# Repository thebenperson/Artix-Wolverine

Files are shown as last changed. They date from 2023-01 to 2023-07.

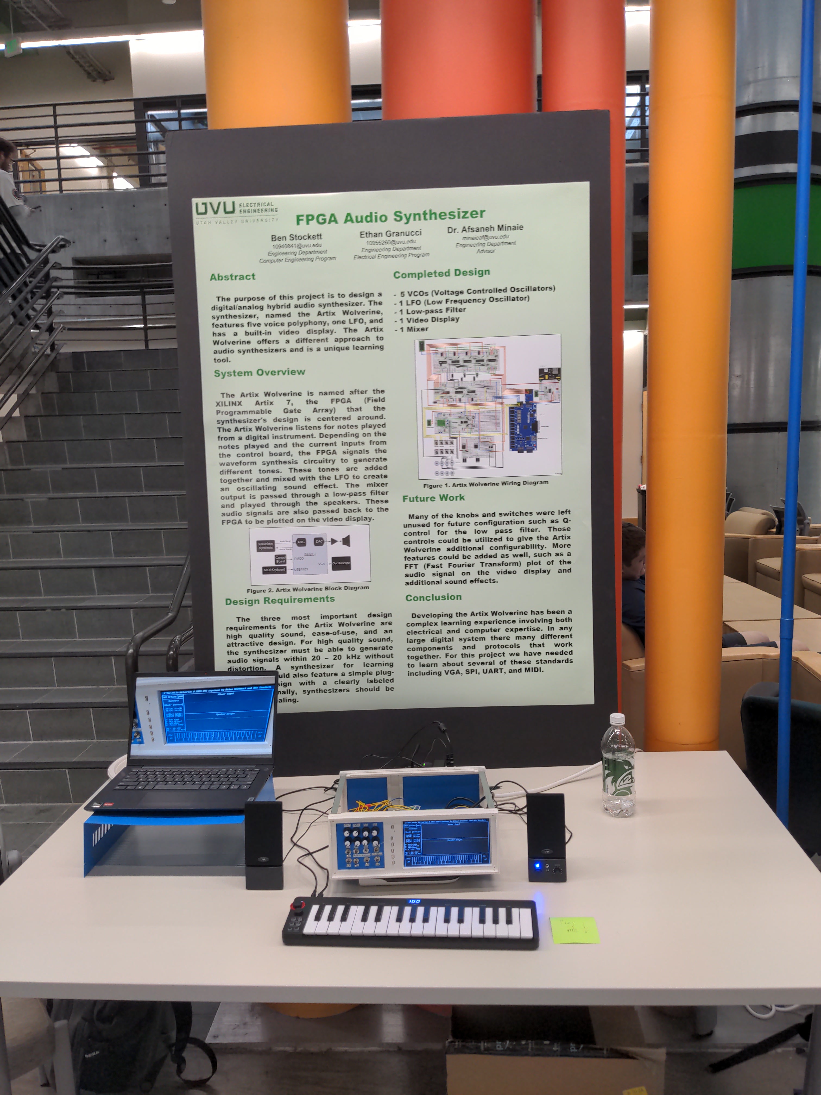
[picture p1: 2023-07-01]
Capstone Day.jpg

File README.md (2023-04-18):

# Artix Wolverine
## 2023 UVU Capstone Project
### Ethan Granucci and Ben Stockett

---

### Project Structure:

```
.
├── bin
│   └── *
├── Makefile
├── README.md
├── res
│   ├── font.psfu
│   └── text.txt
├── src
│   ├── adc.sv
│   ├── agv.sv
│   ├── constraints.xdc
│   ├── dac.sv
│   ├── font.hex
│   ├── font.sv
│   ├── midi.sv
│   ├── oediv.sv
│   ├── text.hex
│   └── top.sv
├── tests
│   └── *
├── tools
│   ├── genfont.sh
│   ├── gentext.sh
│   └── midi.sh
└── Wiring Diagram.fzz
```

### `bin/`: Executables

---

`Makefile`: A [Makefile](https://www.gnu.org/software/make) to build simulations with the [Icarus Verilog](http://iverilog.icarus.com) simulator.

`README.md`: This document.

---

### `res/`: Data and resources
- `font.psfu`: The [PC screen font](https://en.wikipedia.org/wiki/PC_Screen_Font) used in this project.
- `text.txt`: Static text to be displayed on the screen.

---

### `src/`: Project sources
- `adc.sv`: Logic for the analog to digital converter.
- `agv.sv`: Generation of VGA timing signals.
- `constraints.xdc`: Maps port names to their corresponding pins on the Basys 3 FPGA.
- `dac.sv`: Logic for the digital to analog converter.
- `font.hex`: Contents of the font ROM.
- `font.sv`: Retrieves bitmaps corresponding to character numbers.
- `midi.sv`: A MIDI reciever module used to detect keyboard events.
- `oediv.sv`: Logic for drawing characters and numbers.
- `text.hex`: Contents of the ROM for static text to be displayed on the screen.
- `top.sv`: The top module.

---

### `tests/`: Testbenches

---

### `tools/`: Various scripts
- `genfont.sh`: A script to extract the characters we want from the font.
- `gentext.sh`: A script to convert an ASCII text file to a binary encoding suitable for this project.
- `midi.sh`: A script to test the MIDI receiver module with [VMPK, a virtual MIDI keyboard](https://vmpk.sourceforge.io).

---

`Wiring Diagram.fzz`: The [Fritzing](https://fritzing.org) wiring diagram for this project.

---

## Icarus Verilog Simulation:

Running `make` in the project directory will build the simulation with the testbench for the top module by default. To change the testbench, set the makefile variable `test`.

> For example, to include the testbench for the font module, run `make test=font`.

Run `make test` to start the simulation.

### Note:

Icarus Verilog has some trouble with files that start with `v`. That's why `agv.sv` is not named `vga.sv` and `oediv.sv` is not named `video.sv`.

---

## Synthesis:

Synthesis needs to be performed in Xilinx Vivado. Run `make export` and import the contents of the `src/` folder into a new Vivado project.

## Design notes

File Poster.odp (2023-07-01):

## FPGA Audio Synthesizer

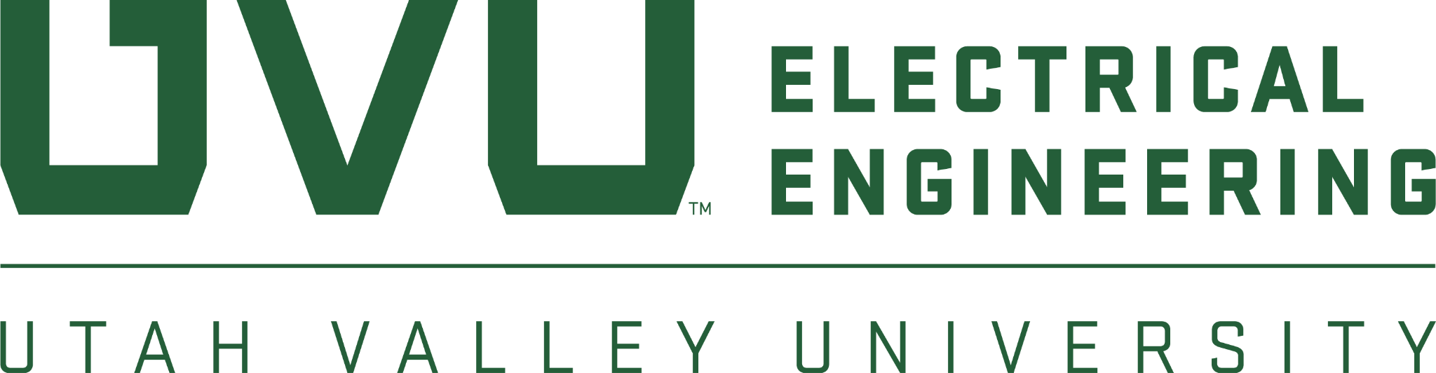
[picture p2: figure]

Ben Stockett

10940841@uvu.edu

Engineering Department

Computer Engineering Program

Abstract

The purpose of this project is to design a digital/analog hybrid audio synthesizer. The synthesizer, named the Artix Wolverine, features five voice polyphony, one LFO, and has a built-in video display. The Artix Wolverine offers a different approach to audio synthesizers and is a unique learning tool.

Ethan Granucci

10955260@uvu.edu

Engineering Department

Electrical Engineering Program

Dr. Afsaneh Minaie

minaieaf@uvu.edu

Engineering Department

Advisor

Completed Design

- 5 VCOs (Voltage Controlled Oscillators)

- 1 LFO (Low Frequency Oscillator)

- 1 Low-pass Filter

- 1 Video Display

- 1 Mixer

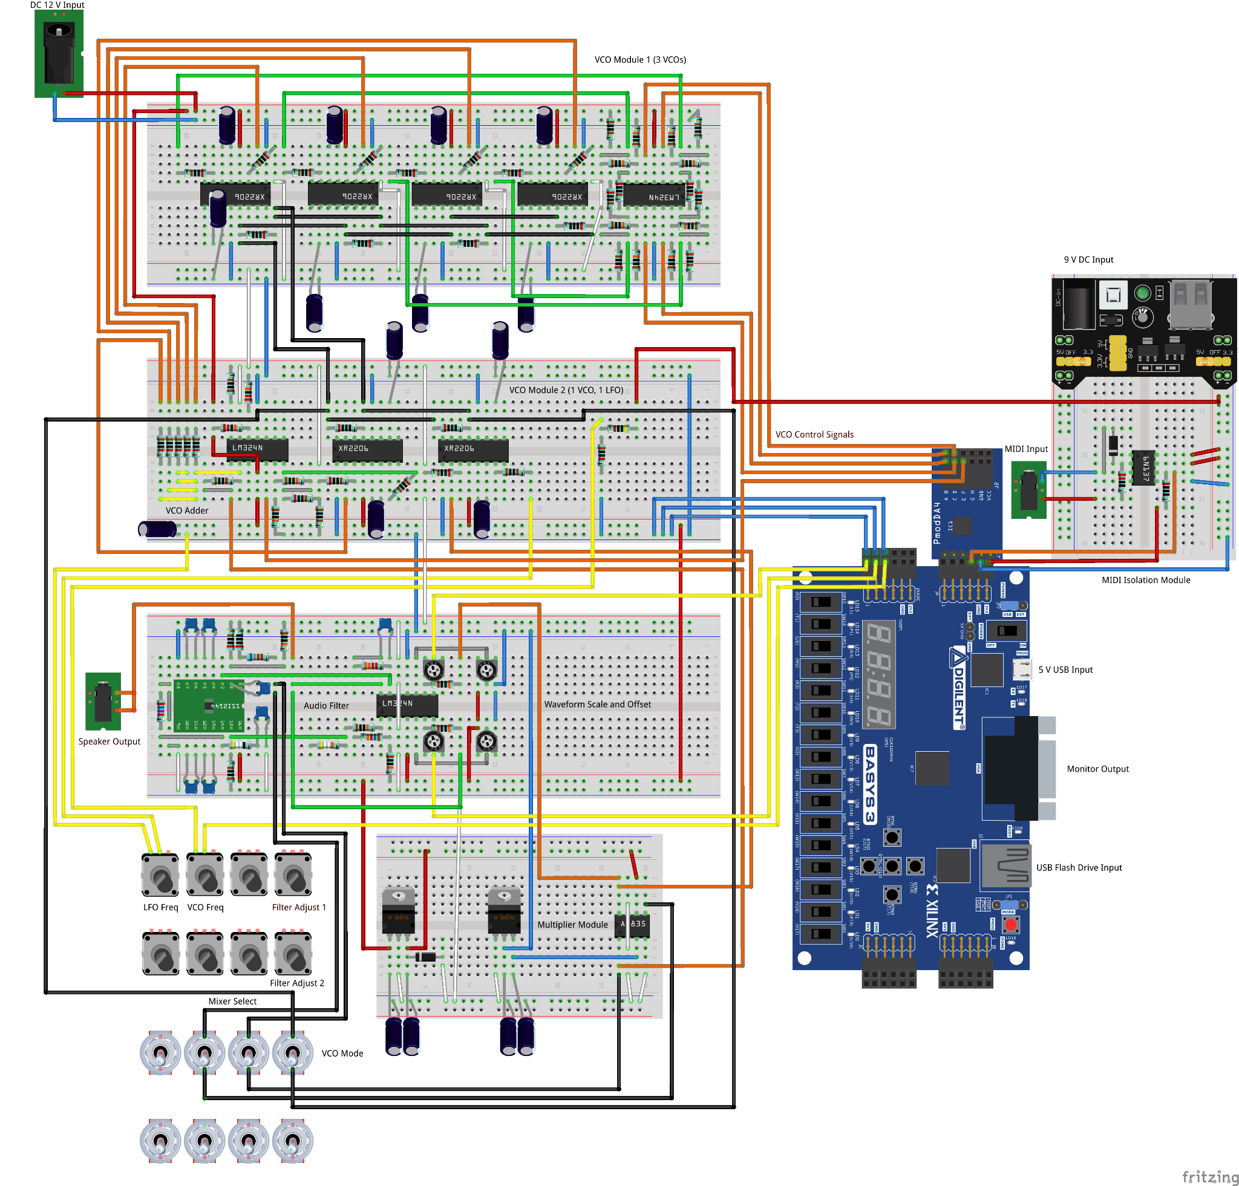
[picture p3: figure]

Figure 1. Artix Wolverine Wiring Diagram

Future Work

Many of the knobs and switches were left unused for future configuration such as Q-control for the low pass filter. Those controls could be utilized to give the Artix Wolverine additional configurability. More features could be added as well, such as a FFT (Fast Fourier Transform) plot of the audio signal on the video display and additional sound effects.

System Overview

The Artix Wolverine is named after the XILINX Artix 7, the FPGA (Field Programmable Gate Array) that the synthesizer's design is centered around. The Artix Wolverine listens for notes played from a digital instrument. Depending on the notes played and the current inputs from the control board, the FPGA signals the waveform synthesis circuitry to generate different tones. These tones are added together and mixed with the LFO to create an oscillating sound effect. The mixer output is passed through a low-pass filter and played through the speakers. These audio signals are also passed back to the FPGA to be plotted on the video display.

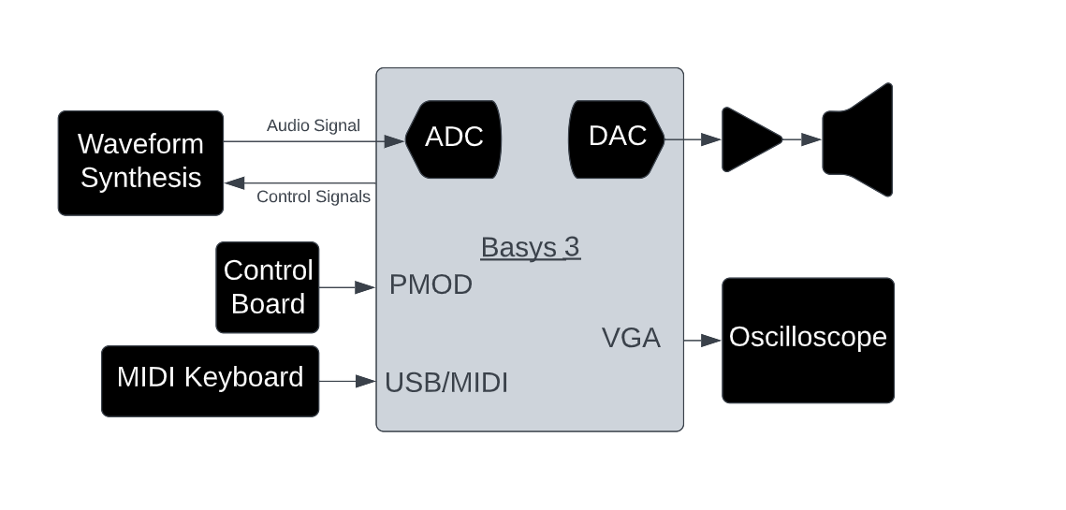
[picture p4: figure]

Figure 2. Artix Wolverine Block Diagram

Design Requirements

The three most important design requirements for the Artix Wolverine are high quality sound, ease-of-use, and an attractive design. For high quality sound, the synthesizer must be able to generate audio signals within 20 – 20 kHz without distortion. A synthesizer for learning purposes should also feature a simple plug-and-play design with a clearly labeled interface. Finally, synthesizers should be visually appealing.

Conclusion

Developing the Artix Wolverine has been a complex learning experience involving both electrical and computer expertise. In any large digital system there many different components and protocols that work together. For this project we have needed to learn about several of these standards including VGA, SPI, UART, and MIDI.

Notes: <number>

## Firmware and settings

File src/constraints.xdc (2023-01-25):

## This file is a general .xdc for the Basys3 rev B board
## To use it in a project:
## - uncomment the lines corresponding to used pins
## - rename the used ports (in each line, after get_ports) according to the top level signal names in the project

## Clock signal
#set_property -dict { PACKAGE_PIN W5   IOSTANDARD LVCMOS33 } [get_ports clk]
#create_clock -add -name sys_clk_pin -period 10.00 -waveform {0 5} [get_ports clk]

 set_property -dict { PACKAGE_PIN W5   IOSTANDARD LVCMOS33 } [get_ports clk]
 create_clock -add -name sys_clk_pin -period 10.00 -waveform {0 5} [get_ports clk]


## Switches
#set_property -dict { PACKAGE_PIN V17   IOSTANDARD LVCMOS33 } [get_ports {sw[0]}]
#set_property -dict { PACKAGE_PIN V16   IOSTANDARD LVCMOS33 } [get_ports {sw[1]}]
#set_property -dict { PACKAGE_PIN W16   IOSTANDARD LVCMOS33 } [get_ports {sw[2]}]
#set_property -dict { PACKAGE_PIN W17   IOSTANDARD LVCMOS33 } [get_ports {sw[3]}]
#set_property -dict { PACKAGE_PIN W15   IOSTANDARD LVCMOS33 } [get_ports {sw[4]}]
#set_property -dict { PACKAGE_PIN V15   IOSTANDARD LVCMOS33 } [get_ports {sw[5]}]
#set_property -dict { PACKAGE_PIN W14   IOSTANDARD LVCMOS33 } [get_ports {sw[6]}]
#set_property -dict { PACKAGE_PIN W13   IOSTANDARD LVCMOS33 } [get_ports {sw[7]}]
#set_property -dict { PACKAGE_PIN V2    IOSTANDARD LVCMOS33 } [get_ports {sw[8]}]
#set_property -dict { PACKAGE_PIN T3    IOSTANDARD LVCMOS33 } [get_ports {sw[9]}]
#set_property -dict { PACKAGE_PIN T2    IOSTANDARD LVCMOS33 } [get_ports {sw[10]}]
#set_property -dict { PACKAGE_PIN R3    IOSTANDARD LVCMOS33 } [get_ports {sw[11]}]
#set_property -dict { PACKAGE_PIN W2    IOSTANDARD LVCMOS33 } [get_ports {sw[12]}]
#set_property -dict { PACKAGE_PIN U1    IOSTANDARD LVCMOS33 } [get_ports {sw[13]}]
#set_property -dict { PACKAGE_PIN T1    IOSTANDARD LVCMOS33 } [get_ports {sw[14]}]
#set_property -dict { PACKAGE_PIN R2    IOSTANDARD LVCMOS33 } [get_ports {sw[15]}]


## LEDs
#set_property -dict { PACKAGE_PIN U16   IOSTANDARD LVCMOS33 } [get_ports {led[0]}]
#set_property -dict { PACKAGE_PIN E19   IOSTANDARD LVCMOS33 } [get_ports {led[1]}]
#set_property -dict { PACKAGE_PIN U19   IOSTANDARD LVCMOS33 } [get_ports {led[2]}]
#set_property -dict { PACKAGE_PIN V19   IOSTANDARD LVCMOS33 } [get_ports {led[3]}]
#set_property -dict { PACKAGE_PIN W18   IOSTANDARD LVCMOS33 } [get_ports {led[4]}]
#set_property -dict { PACKAGE_PIN U15   IOSTANDARD LVCMOS33 } [get_ports {led[5]}]
#set_property -dict { PACKAGE_PIN U14   IOSTANDARD LVCMOS33 } [get_ports {led[6]}]
#set_property -dict { PACKAGE_PIN V14   IOSTANDARD LVCMOS33 } [get_ports {led[7]}]
#set_property -dict { PACKAGE_PIN V13   IOSTANDARD LVCMOS33 } [get_ports {led[8]}]
#set_property -dict { PACKAGE_PIN V3    IOSTANDARD LVCMOS33 } [get_ports {led[9]}]
#set_property -dict { PACKAGE_PIN W3    IOSTANDARD LVCMOS33 } [get_ports {led[10]}]
#set_property -dict { PACKAGE_PIN U3    IOSTANDARD LVCMOS33 } [get_ports {led[11]}]
#set_property -dict { PACKAGE_PIN P3    IOSTANDARD LVCMOS33 } [get_ports {led[12]}]
#set_property -dict { PACKAGE_PIN N3    IOSTANDARD LVCMOS33 } [get_ports {led[13]}]
#set_property -dict { PACKAGE_PIN P1    IOSTANDARD LVCMOS33 } [get_ports {led[14]}]
#set_property -dict { PACKAGE_PIN L1    IOSTANDARD LVCMOS33 } [get_ports {led[15]}]


##7 Segment Display
#set_property -dict { PACKAGE_PIN W7   IOSTANDARD LVCMOS33 } [get_ports {seg[0]}]
#set_property -dict { PACKAGE_PIN W6   IOSTANDARD LVCMOS33 } [get_ports {seg[1]}]
#set_property -dict { PACKAGE_PIN U8   IOSTANDARD LVCMOS33 } [get_ports {seg[2]}]
#set_property -dict { PACKAGE_PIN V8   IOSTANDARD LVCMOS33 } [get_ports {seg[3]}]
#set_property -dict { PACKAGE_PIN U5   IOSTANDARD LVCMOS33 } [get_ports {seg[4]}]
#set_property -dict { PACKAGE_PIN V5   IOSTANDARD LVCMOS33 } [get_ports {seg[5]}]
#set_property -dict { PACKAGE_PIN U7   IOSTANDARD LVCMOS33 } [get_ports {seg[6]}]

#set_property -dict { PACKAGE_PIN V7   IOSTANDARD LVCMOS33 } [get_ports dp]

#set_property -dict { PACKAGE_PIN U2   IOSTANDARD LVCMOS33 } [get_ports {an[0]}]
#set_property -dict { PACKAGE_PIN U4   IOSTANDARD LVCMOS33 } [get_ports {an[1]}]
#set_property -dict { PACKAGE_PIN V4   IOSTANDARD LVCMOS33 } [get_ports {an[2]}]
#set_property -dict { PACKAGE_PIN W4   IOSTANDARD LVCMOS33 } [get_ports {an[3]}]


##Buttons
#set_property -dict { PACKAGE_PIN U18   IOSTANDARD LVCMOS33 } [get_ports btnC]
#set_property -dict { PACKAGE_PIN T18   IOSTANDARD LVCMOS33 } [get_ports btnU]
#set_property -dict { PACKAGE_PIN W19   IOSTANDARD LVCMOS33 } [get_ports btnL]
#set_property -dict { PACKAGE_PIN T17   IOSTANDARD LVCMOS33 } [get_ports btnR]
#set_property -dict { PACKAGE_PIN U17   IOSTANDARD LVCMOS33 } [get_ports btnD]
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

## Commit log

2023-02-15 Added ADC module and waveform plotting. Added Blender enclosure model.
    [Enclosure.blend, Wiring Diagram.fzz]
2023-04-12 Saved progress.
    [Wiring Diagram.fzz]
2023-04-18 Updated to reflect current design.
    [Enclosure.blend]
